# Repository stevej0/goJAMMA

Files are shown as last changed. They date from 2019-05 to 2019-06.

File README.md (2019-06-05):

# goJAMMA
Game on JAMMA development board PROTOTYPE v0.2 (C) 2019 Steve Jones / BONEYARD

This is a prototype FPGA based JAMMA board for the development of homebrew games for arcade machine platforms and superguns.

The design is currently in a prototype stage, pretty much everything has been tested as working, however bugs and performance issues may remain. This design is NOT approved for production as of yet, but the files are made public as an aid to others developing their own hardware.
  
FAQ to follow...

Hardware specifications (fixed):

Altera MAX10 10M25SAE FPGA, 25K logic elements, extended Flash features  
1MB 8Bit Static RAM, 10ns access  
16MB 8Bit HyperRAM, 166Mhz DDR, 128 byte burst  
48Mhz Crystal clock oscillator  
microSD card interface  
ADC 4 channel, 10 bit analog to digital convertor (Analog inputs via expansion connector)  
Buffered video output  
Stereo audio amplifier, 11 Watts  
PCM5101 Stereo 12S DAC  
4 Way Dip Switch  
Standard JAMMA 5v tolerant inputs, plus configuration jumpers for 6-button Pandoras Box style interface  
1x USER button, 1x RESET button  
1x USER LED  
Large long-life and user replacable through hole capacitors in the audio and voltage regulator sections  

Homebrew logic core (basic wishlist) specifications, likely to change:
  
CPU core (undecided, but a 6502 at 4Mhz currently works well)  
256 Colour palette, 320 x 240 pixel framebuffer (double buffered)  
Sprites (undecided, most likely a blitter for the framebuffer with fast HyperRAM as gfx data source)  
Layers (undecided, at least one text overlay, maybe a tiled background layer also)  
16 channel sample playback  
Ability to load programs and data from microSD fat32 formatted cards

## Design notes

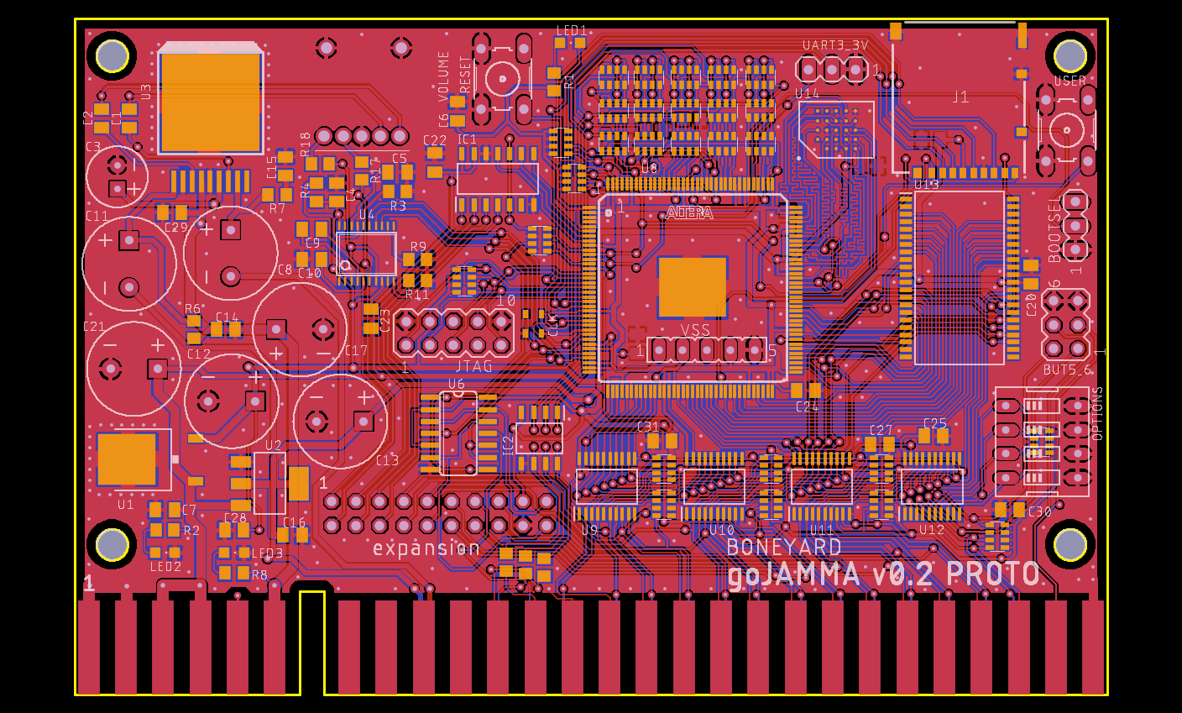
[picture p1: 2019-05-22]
pcb/goJAMMAv02a.png

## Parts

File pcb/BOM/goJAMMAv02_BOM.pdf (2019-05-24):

QTY | PART | VALUE | DEVICE | DESCRIPTION | MOUSER PART NUMBER
1 | C3 | 100uF | ULD1E101MED1TD | 100µF 25V polarized capacitor, Nichicon, 10000hr, 6.5mm x 12.5mm | 647-ULD1E101MED1TD
9 | C1, C2, C4, C5, C7, C14, C15, C16, C28 | 100nF | C0805C104M5R | CAPACITOR, KEMET, MLCC, 100nf, 50V, X7R, 0805 | 80-C0805C104M5R
2 | C9, C10 | 2u2 | C0805C225K3P | CAPACITOR, KEMET, MLCC, 2.2uf, 25V, X5R, 0805 | 80-C0805C225K3P
14 | C6, C18, C19, C20, C22, C23, C24, C25, C26, C27, C29, C30, C31, C33 | 1uF | C0805C105Z4V | CAPACITOR, KEMET, MLCC, 1uf, 16V, Y5V, 0805 | 80-C0805C105Z4V
4 | C12, C13, C17, C21 | 100uF | UBT1V101MPD8 | 100µF 35V polarized capacitor, Nichicon, 5000hr, 10mm x 12.5mm | 647-UBT1V101MPD8
2 | C8, C11 | 1000uF | EKYB250E102MJ20S | 1000µF 25V polarized capacitor, ChemiCon, 10000hr, 10mm x 20mm | 661-EKYB250E102MJ20S
3 | LED1, LED2, LED3 | LEDCHIP_0805 | 150080YS75000 | LED, 0805, YELLOW | 710-150080YS75000
1 | R2 | 150R | CRCW0805150RFKEA | RESISTOR, 150R, 0805, 1/8W, 1% | 71-CRCW0805-150-E3
1 | R8 | 560R | CRCW0805560RJNEA | RESISTOR, 560R, 0805, 1/8W, 5% | 71-CRCW0805560RJNEA
7 | R1, R2, R3, R4, R8, R9, R11 | 1K | CRCW08051K00FKEAC | RESISTOR, 1K, 0805, 1/8W, 1% | 71-CRCW08051K00FKEAC
3 | R5, R12, R13 | 0R | CRCW08050000Z0EAC | RESISTOR, 0R, 0805, 1/8W, 1% | 71-CRCW08050000Z0EAC
2 | R6, R7 | 2R7 | CRGS0805J2R7 | RESISTOR, 2.7R, 0805, 500mW, 5% | 279-CRGS0805J2R7
3 | R14, R15, R16 | 3K3 | CRCW08053K30FKEAC | RESISTOR, 3.3K, 0805, 1/8W, 1% | 71-CRCW08053K30FKEAC
2 | R17, R18 | 1M | CRCW08051M00FKEA | RESISTOR, 1M, 0805, 1/8W, 1% | 71-CRCW0805-1.0M-E3
15 | RN1, RN2, RN3, RN4, RN5, RN6, RN7, RN8, RN9, RN10, RN11, RN12, RN13, RN14, RN15 | 1k x 4 | YC164-FR-071KL | RESISTOR ARRAY 4way, 1K, 1%, 1206 | 603-YC164-FR-071KL
12 | RN16, RN17, RN18, RN19, RN20, RN21, RN22, RN23, RN24, RN26, RN27, RN28 | 1k x 4 | EXB-V8V102JV | RESISTOR ARRAY 4way, 1K, 5%, 1206 | 667-EXB-V8V102JV
1 | CLK | ECS-3225MV-480-CN-TR | ECS-3225MV-480-CN-TR | 3.3Vdc 48Mhz SMD Crystal clock oscillator 3.2 mm x 2.5 mm | 520-3225MV-480-CNT
1 | IC1 | MCP3004-I_SL | MCP3004-I_SL | A/D Converter 10Bit 4-ch 2.7V SPI SOIC14 | 579-MCP3004-I/SL
1 | IC2 | THS7314D | THS7314D | Video Amp 3-channel, SOIC8 | 595-THS7314D
1 | U1 | BA33BC0FP-E2 | BA33BC0FP-E2 | Voltage Regulator 3.3v positive, 1A, TO-252-3 | 755-BA33BC0FP-E2
1 | U2 | LM1117MPX1.8NOPB | V_REG_LM1117SOT223 | Voltage Regulator 1.8v positive, 800ma, LM1117, SOT-223-4 | 926-LM1117MPX1.8NOPB
1 | U3 | LM4755TSX/NOPB | LM4755TSX/NOPB | LM4755 Stereo Audio Amp, 11W, TO-263-9 | 926-LM4755TSX/NOPB
1 | U4 | PCM5101 | PCM5101 | Stereo Audio D/A Converter | 595-PCM5101APWR
1 | U6 | 74HC08D,653 | 74HC08D,653 | Quad 2-input AND gate, HC08 | 771-74HC08D-T
1 | U8 | 10M25SAE144C8G | 10M25SAE144C8G | ALTERA MAX10 FPGA 25K LE, FLASH, ANALOG | 989-10M25SAE144C8G
4 | U9, U10, U11, U12 | SN74LV245APWR | SN74LV245APWR | Octal Bus Transceivers With 3-State Outputs | 595-SN74LV245APWR
1 | U13 | IS61WV10248EDBLL-10TLI | IS61WV10248EDBLL-10TLI | SRAM 8M, 2.4V-3.6V, 10ns LP Async SRAM | 870-61WV10EDBLL10TLI
1 | U14 | IS66WVH16M8ALL-166B1LI | IS66WVH16M8ALL-166B1LI | DRAM 128Mb 16Mbx8 1.8V 166MHz HyperRAM | 870-WVH16M8AL166B1LI
1 | OPTIONS | SW_DIP-4 | NDS-04V | DIP SWITCH, 4 Position, Diptronics | 113-NDS-04V
2 | RESET, USER | SWITCH | B3F-1000 | OMRON TACT SWITCH 6mm x 6mm | 653-B3F-1000
1 | VOLUME | RK14J12A0A0K | RK14J12A0A0K | Potentiometers Dual Unit 14mm 3B insertion (2mm) | 688-RK14J12A0A0K
1 | J1 | DM3AT-SF-PEJM5 | DM3AT-SF-PEJM5 | DM3 RA SMT microSD memory card push/push | 798-DM3AT-SF-PEJM5
1 | JTAG | 5 x 2 | MA05-2 | PIN HEADER, 10 way
2 | BOOTSEL, UART3_3V | 3 x 1 | MA03-1 | PIN HEADER, 3 way
1 | BUT5_6 | 3 x 2 | MA03-2 | PIN HEADER, 6 way
1 | SV2 | 10 x 2 | MA10-2 | PIN HEADER, 20 way
1 | SV3 | 5 x 1 | MA05-1 | PIN HEADER, 5 way

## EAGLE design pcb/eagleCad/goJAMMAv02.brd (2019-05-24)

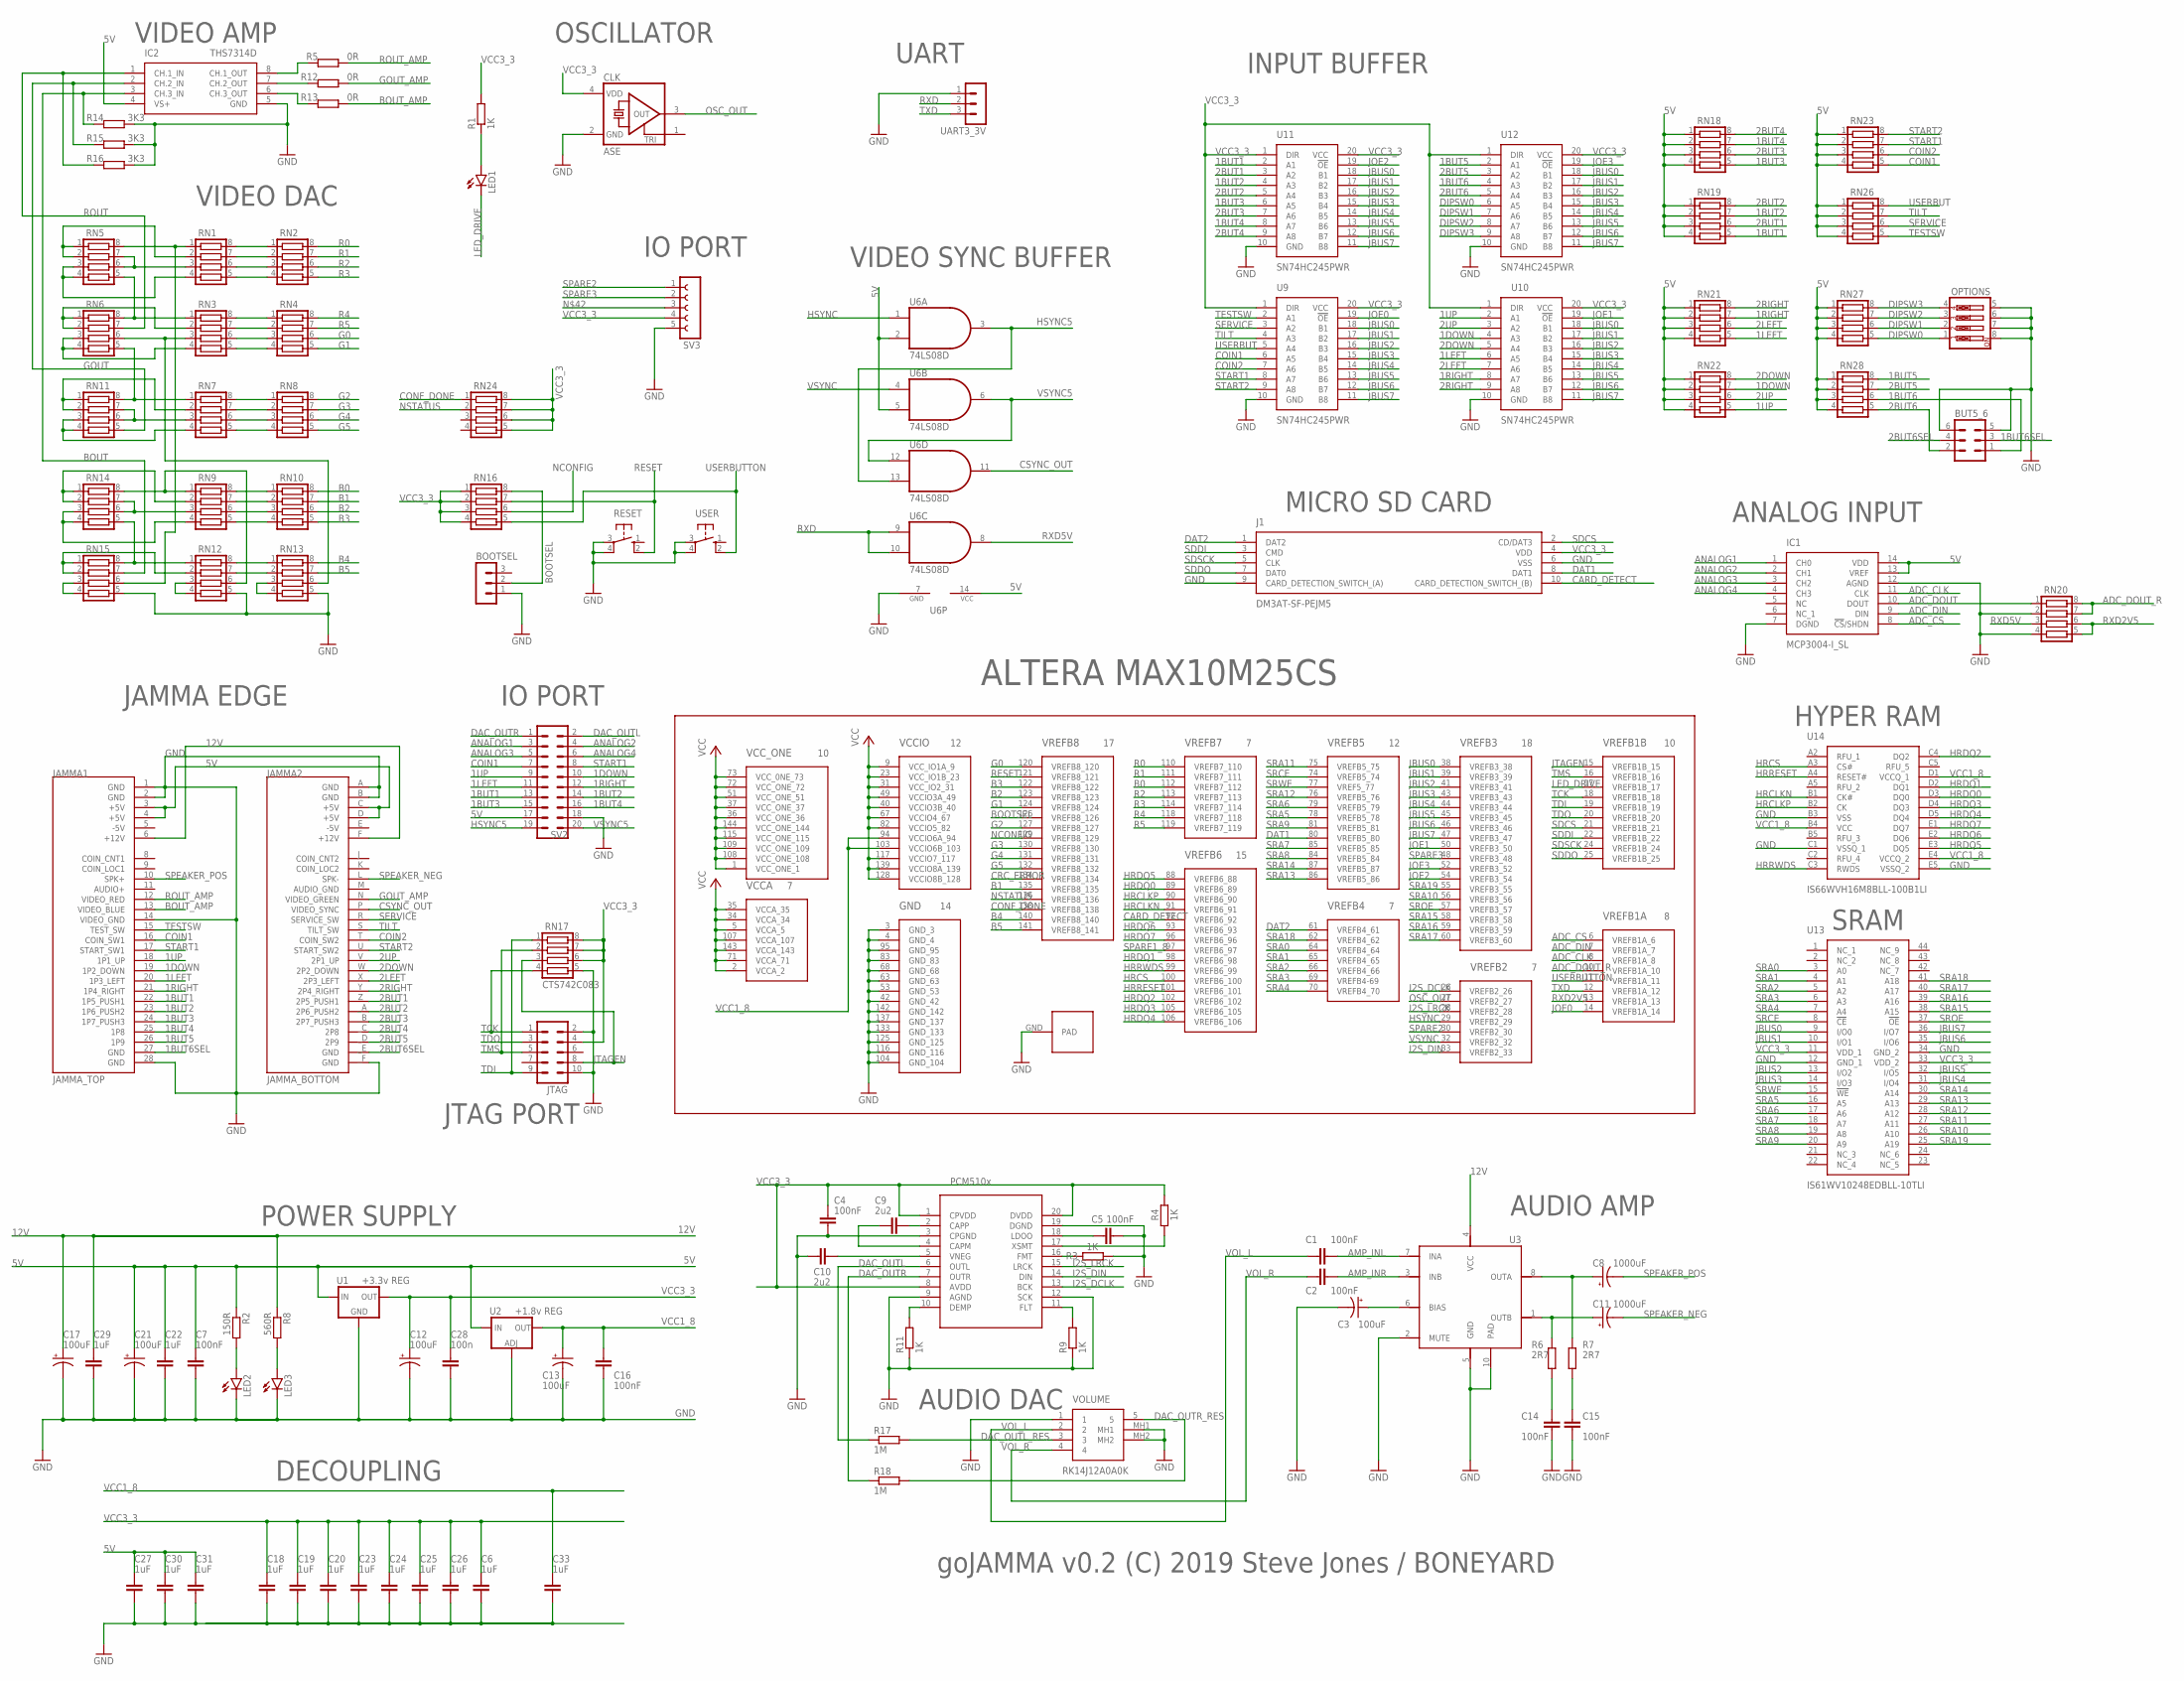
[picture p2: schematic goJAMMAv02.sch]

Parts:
BOOTSEL: MA03-1
BUT5_6: MA03-2
C1, C2, C4, C5, C7, C14, C15, C16: 100nF; C0805K
C3: 100uF; CPOL-RADIAL-2.5MM-6.5MM
C6, C18, C19, C20, C22, C23, C24, C25, C26, C27, C29, C30, C31, C33: 1uF; C0805K
C8, C11: 1000uF; CPOL-RADIAL-5MM-10MM
C9, C10: 2u2; C0805K
C12, C13, C17, C21: 100uF; CPOL-RADIAL-5MM-10MM
C28: 100n; C0805K
CLK: ASE
IC1: MCP3004-I_SL; SOIC127P600X175-14N
IC2: THS7314D; SOIC127P600X175-8N
J1: DM3AT-SF-PEJM5; DM3AT-SF-PEJM5_1
JAMMA1: JAMMA_TOP
JAMMA2: JAMMA_BOTTOM
JTAG: MA05-2
LED1, LED2, LED3: LEDCHIPLED_0805; CHIPLED_0805
OPTIONS: SW_DIP-4; EDG-04
R1, R3, R4, R9, R11: 1K; R0805
R2: 150R; R0805
R5, R12, R13: 0R; R0805
R6, R7: 2R7; R0805
R8: 560R; R0805
R14, R15, R16: 3K3; R0805
R17, R18: 1M; R0805
RESET: 10-XX; B3F-10XX
RN1, RN2, RN3, RN4, RN5, RN6, RN7, RN8, RN9, RN10, RN11, RN12, RN13, RN14, RN15, RN16, RN17, RN18, RN19, RN20, RN21, RN22, RN23, RN24, RN26, RN27, RN28: CTS742C083
SV2: MA10-2
SV3: FE05-1
U1: +3.3v REG; TO-252
U2: +1.8v REG; SOT223
U3: LM4755; DDPAK-9
U4: PCM5101; TSSOP20
U6: 74LS08D; SO14
U8: ALTERA_MAX10M25SCPAD; ALTERA_EQFP144
U9, U10, U11, U12: SN74HC245PWR; SOP65P640X120-20N
U13: IS61WV10248EDBLL-10TLI; SOP80P1176X120-44N
U14: IS66WVH16M8BLL-100B1LI; BGA24C100P5X5_600X800X120
UART3_3V: MA03-1
USER: 10-XX; B3F-10XX
VOLUME: RK14J12A0A0K

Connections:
1BUT1: JAMMA1.22 (1P5_PUSH1), RN19.5, SV2.13, U11.2 (A1)
1BUT2: JAMMA1.23 (1P6_PUSH2), RN19.7, SV2.14, U11.4 (A3)
1BUT3: JAMMA1.24 (1P7_PUSH3), RN18.5, SV2.15, U11.6 (A5)
1BUT4: JAMMA1.25 (1P8), RN18.7, SV2.16, U11.8 (A7)
1BUT5: JAMMA1.26 (1P9), RN28.8, U12.2 (A1)
1BUT6: BUT5_6.1, RN28.6, U12.4 (A3)
1BUT6SEL: BUT5_6.3, JAMMA1.27 (GND)
1DOWN: JAMMA1.19 (1P2_DOWN), RN22.7, SV2.10, U10.4 (A3)
1LEFT: JAMMA1.20 (1P3_LEFT), RN21.5, SV2.11, U10.6 (A5)
1RIGHT: JAMMA1.21 (1P4_RIGHT), RN21.7, SV2.12, U10.8 (A7)
1UP: JAMMA1.18 (1P1_UP), RN22.5, SV2.9, U10.2 (A1)
2BUT1: JAMMA2.Z (2P5_PUSH1), RN19.6, U11.3 (A2)
2BUT2: JAMMA2._A (2P6_PUSH2), RN19.8, U11.5 (A4)
2BUT3: JAMMA2._B (2P7_PUSH3), RN18.6, U11.7 (A6)
2BUT4: JAMMA2._C (2P8), RN18.8, U11.9 (A8)
2BUT5: JAMMA2._D (2P9), RN28.7, U12.3 (A2)
2BUT6: BUT5_6.2, RN28.5, U12.5 (A4)
2BUT6SEL: BUT5_6.4, JAMMA2._E (GND)
2DOWN: JAMMA2.W (2P2_DOWN), RN22.8, U10.5 (A4)
2LEFT: JAMMA2.X (2P3_LEFT), RN21.6, U10.7 (A6)
2RIGHT: JAMMA2.Y (2P4_RIGHT), RN21.8, U10.9 (A8)
2UP: JAMMA2.V (2P1_UP), RN22.6, U10.3 (A2)
5V: C7.1, C21.+, C22.1, C27.1, C30.1, C31.1, IC1.13 (VREF), IC1.14 (VDD), IC2.4 (VS+), JAMMA1.3 (+5V), JAMMA1.4 (+5V), JAMMA2.C (+5V), JAMMA2.D (+5V), R2.1, RN18.1, RN18.2, RN18.3, RN18.4, RN19.1, RN19.2, RN19.3, RN19.4, RN21.1, RN21.2, RN21.3, RN21.4, RN22.1, RN22.2, RN22.3, RN22.4, RN23.1, RN23.2, RN23.3, RN23.4, RN26.1, RN26.2, RN26.3, RN26.4, RN27.1, RN27.2, RN27.3, RN27.4, RN28.1, RN28.2, RN28.3, RN28.4, SV2.17, U1.1 (IN), U2.3 (IN), U6.2 (I1), U6.5 (I1), U6.14 (VCC)
12V: C17.+, C29.1, JAMMA1.6 (+12V), JAMMA2.F (+12V), R8.1, U3.4 (VCC)
-5V: JAMMA1.5 (-5V), JAMMA2.E (-5V)
ADC_CLK: IC1.11 (CLK), U8.8 (VREFB1A_8)
ADC_CS: IC1.8 (!CS!/SHDN), U8.6 (VREFB1A_6)
ADC_DIN: IC1.9 (DIN), U8.7 (VREFB1A_7)
ADC_DOUT: IC1.10 (DOUT), RN20.1
ADC_DOUT_R: RN20.7, RN20.8, U8.10 (VREFB1A_10)
AMP_INL: C1.2, U3.7 (INA)
AMP_INR: C2.2, U3.3 (INB)
ANALOG1: IC1.1 (CH0), SV2.3
ANALOG2: IC1.2 (CH1), SV2.4
ANALOG3: IC1.3 (CH2), SV2.5
ANALOG4: IC1.4 (CH3), SV2.6
B0: RN10.8, U8.112 (VREFB7_112)
B1: RN10.7, U8.135 (VREFB8_135)
B2: RN10.6, U8.123 (VREFB8_123)
B3: RN10.5, U8.122 (VREFB8_122)
B4: RN13.8, U8.140 (VREFB8_140)
B5: RN13.7, U8.141 (VREFB8_141)
BOOTSEL: BOOTSEL.2, RN16.8, U8.126 (VREFB8_126)
BOUT: IC2.3 (CH.3_IN), R14.2, RN15.7
BOUT_AMP: JAMMA1.13 (VIDEO_BLUE), R13.2
CARD_DETECT: J1.10 (CARD_DETECTION_SWITCH_(B)), U8.92 (VREFB6_92)
COIN1: JAMMA1.16 (COIN_SW1), RN23.5, SV2.7, U9.6 (A5)
COIN2: JAMMA2.T (COIN_SW2), RN23.6, U9.7 (A6)
CONF_DONE: RN24.1, U8.138 (VREFB8_138)
CRC_ERROR: U8.134 (VREFB8_134)
CSYNC_OUT: JAMMA2.P (VIDEO_SYNC), U6.11 (O)
DAC_OUTL: R17.1, SV2.2, U4.6 (OUTL)
DAC_OUTL_RES: R17.2, VOLUME.3
DAC_OUTR: R18.1, SV2.1, U4.7 (OUTR)
DAC_OUTR_RES: R18.2, VOLUME.5
DAT1: J1.8 (DAT1), U8.80 (VREFB5_80)
DAT2: J1.1 (DAT2), U8.61 (VREFB4_61)
DIPSW0: OPTIONS.1, RN27.5, U12.6 (A5)
DIPSW1: OPTIONS.2, RN27.6, U12.7 (A6)
DIPSW2: OPTIONS.3, RN27.7, U12.8 (A7)
DIPSW3: OPTIONS.4, RN27.8, U12.9 (A8)
G0: RN4.6, U8.120 (VREFB8_120)
G1: RN4.5, U8.124 (VREFB8_124)
G2: RN8.8, U8.127 (VREFB8_127)
G3: RN8.7, U8.130 (VREFB8_130)
G4: RN8.6, U8.131 (VREFB8_131)
G5: RN8.5, U8.132 (VREFB8_132)
GND: BOOTSEL.1, BUT5_6.5, BUT5_6.6, C3.2 (-), C4.2, C5.2, C6.2, C7.2, C10.2, C12.-, C13.-, C14.2, C15.2, C16.2, C17.-, C18.2, C19.2, C20.2, C21.-, C22.2, C23.2, C24.2, C25.2, C26.2, C27.2, C28.2, C29.2, C30.2, C31.2, C33.2, CLK.2 (GND), IC1.7 (DGND), IC1.12 (AGND), IC2.5 (GND), J1.6 (VSS), J1.9 (CARD_DETECTION_SWITCH_(A)), JAMMA1.1 (GND), JAMMA1.2 (GND), JAMMA1.14 (VIDEO_GND), JAMMA1.28 (GND), JAMMA2.A (GND), JAMMA2.B (GND), JAMMA2._F (GND), JTAG.2, JTAG.10, LED2.C, LED3.C, OPTIONS.5, OPTIONS.6, OPTIONS.7, OPTIONS.8, R3.1, R9.1, R11.1, R14.1, R15.1, R16.1, RESET.3, RESET.4 (P1), RN12.5, RN13.5, RN15.5, RN17.5, RN20.2, RN20.4, SV2.18, SV3.5, U1.3 (GND), U2.1 (ADJ), U3.2 (MUTE), U3.5 (GND), U3.10 (PAD), U4.3 (CPGND), U4.9 (AGND), U4.12 (SCK), U4.19 (DGND), U6.7 (GND), U8.3 (GND_3), U8.4 (GND_4), U8.42 (GND_42), U8.53 (GND_53), U8.63 (GND_63), U8.68 (GND_68), U8.83 (GND_83), U8.95 (GND_95), U8.104 (GND_104), U8.116 (GND_116), U8.125 (GND_125), U8.133 (GND_133), U8.137 (GND_137), U8.142 (GND_142), U8.GND (PAD), U9.10 (GND), U10.10 (GND), U11.10 (GND), U12.10 (GND), U13.12 (GND_1), U13.34 (GND_2), U14.B3 (VSS), U14.C1 (VSSQ_1), U14.E5 (VSSQ_2), UART3_3V.1, USER.3, USER.4 (P1), VOLUME.1, VOLUME.MH1, VOLUME.MH2
GOUT: IC2.2 (CH.2_IN), R15.2, RN11.5
GOUT_AMP: JAMMA2.N (VIDEO_GREEN), R12.2
HRCLKN: U8.91 (VREFB6_91), U14.B1 (CK#)
HRCLKP: U8.90 (VREFB6_90), U14.B2 (CK)
HRCS: U8.100 (VREFB6_100), U14.A3 (CS#)
HRDQ0: U8.89 (VREFB6_89), U14.D3 (DQ0)
HRDQ1: U8.98 (VREFB6_98), U14.D2 (DQ1)
HRDQ2: U8.102 (VREFB6_102), U14.C4 (DQ2)
HRDQ3: U8.105 (VREFB6_105), U14.D4 (DQ3)
HRDQ4: U8.106 (VREFB6_106), U14.D5 (DQ4)
HRDQ5: U8.88 (VREFB6_88), U14.E3 (DQ5)
HRDQ6: U8.93 (VREFB6_93), U14.E2 (DQ6)
HRDQ7: U8.96 (VREFB6_96), U14.E1 (DQ7)
HRRESET: U8.101 (VREFB6_101), U14.A4 (RESET#)
HRRWDS: U8.99 (VREFB6_99), U14.C3 (RWDS)
HSYNC: U6.1 (I0), U8.29 (VREFB2_29)
HSYNC5: SV2.19, U6.3 (O), U6.13 (I1)
I2S_DCLK: U4.13 (BCK), U8.26 (VREFB2_26)
I2S_DIN: U4.14 (DIN), U8.33 (VREFB2_33)
I2S_LRCK: U4.15 (LRCK), U8.28 (VREFB2_28)
JBUS0: U8.38 (VREFB3_38), U9.18 (B1), U10.18 (B1), U11.18 (B1), U12.18 (B1), U13.9 (I/O0)
JBUS1: U8.39 (VREFB3_39), U9.17 (B2), U10.17 (B2), U11.17 (B2), U12.17 (B2), U13.10 (I/O1)
JBUS2: U8.41 (VREFB3_41), U9.16 (B3), U10.16 (B3), U11.16 (B3), U12.16 (B3), U13.13 (I/O2)
JBUS3: U8.43 (VREFB3_43), U9.15 (B4), U10.15 (B4), U11.15 (B4), U12.15 (B4), U13.14 (I/O3)
JBUS4: U8.44 (VREFB3_44), U9.14 (B5), U10.14 (B5), U11.14 (B5), U12.14 (B5), U13.31 (I/O4)
JBUS5: U8.45 (VREFB3_45), U9.13 (B6), U10.13 (B6), U11.13 (B6), U12.13 (B6), U13.32 (I/O5)
JBUS6: U8.46 (VREFB3_46), U9.12 (B7), U10.12 (B7), U11.12 (B7), U12.12 (B7), U13.35 (I/O6)
JBUS7: U8.47 (VREFB3_47), U9.11 (B8), U10.11 (B8), U11.11 (B8), U12.11 (B8), U13.36 (I/O7)
JOE0: U8.14 (VREFB1A_14), U9.19 (!OE)
JOE1: U8.50 (VREFB3_50), U10.19 (!OE)
JOE2: U8.54 (VREFB3_54), U11.19 (!OE)
JOE3: U8.52 (VREFB3_52), U12.19 (!OE)
JTAGEN: JTAG.8, RN17.3, U8.15 (VREFB1B_15)
LED_DRIVE: LED1.C, U8.17 (VREFB1B_17)
unnamed: RN1.8, RN2.1
unnamed: C8.+, R7.2, U3.8 (OUTA)
unnamed: RN1.7, RN2.2
unnamed: RN1.6, RN2.3
unnamed: RN1.5, RN2.4
unnamed: RN3.8, RN4.1
unnamed: RN3.7, RN4.2
unnamed: RN7.8, RN8.1
unnamed: RN7.7, RN8.2
unnamed: RN7.6, RN8.3
unnamed: RN7.5, RN8.4
unnamed: RN6.5, RN7.1, RN11.8
unnamed: RN9.8, RN10.1
unnamed: RN1.1, RN5.8, RN15.6
unnamed: RN1.2, RN5.1, RN5.2
unnamed: RN1.3, RN5.6, RN5.7
unnamed: RN1.4, RN5.3, RN5.4
unnamed: RN3.1, RN5.5, RN6.8
unnamed: RN3.2, RN6.1, RN6.2
unnamed: RN9.7, RN10.2
unnamed: RN7.2, RN11.1, RN11.2
unnamed: RN7.3, RN11.6, RN11.7
unnamed: RN7.4, RN11.3, RN11.4
unnamed: RN9.6, RN10.3
unnamed: RN9.5, RN10.4
unnamed: RN3.4, RN6.3, RN6.4
unnamed: RN12.8, RN13.1
unnamed: RN3.6, RN4.3
unnamed: RN3.5, RN4.4
unnamed: RN3.3, RN6.6, RN13.6
unnamed: RN12.7, RN13.2
unnamed: RN9.1, RN12.6, RN14.8
unnamed: RN9.2, RN14.1, RN14.2
unnamed: RN9.3, RN14.6, RN14.7
unnamed: RN9.4, RN14.3, RN14.4
unnamed: RN12.1, RN14.5, RN15.8
unnamed: RN12.2, RN15.1, RN15.2
unnamed: RN15.3, RN15.4
unnamed: RN12.3, RN12.4
unnamed: RN13.3, RN13.4
unnamed: R3.2, U4.16 (FMT)
unnamed: IC2.8 (CH.1_OUT), R5.1
unnamed: LED1.A, R1.1
unnamed: IC2.7 (CH.2_OUT), R12.1
unnamed: IC2.6 (CH.3_OUT), R13.1
unnamed: LED2.A, R2.2
unnamed: LED3.A, R8.2
unnamed: C9.2, U4.2 (CAPP)
unnamed: C9.1, U4.4 (CAPM)
unnamed: C11.+, R6.2, U3.1 (OUTB)
unnamed: C3.1 (+), U3.6 (BIAS)
unnamed: C14.1, R6.1
unnamed: C15.1, R7.1
unnamed: C10.1, U4.5 (VNEG)
unnamed: R4.1, U4.17 (XSMT)
unnamed: R11.2, U4.10 (DEMP)
unnamed: R9.2, U4.11 (FLT)
unnamed: C5.1, U4.18 (LDOO)
NCONFIG: RN16.6, U8.129 (VREFB8_129)
NSTATUS: RN24.2, U8.136 (VREFB8_136)
OSC_OUT: CLK.3 (OUT), U8.27 (VREFB2_27)
R0: RN2.8, U8.110 (VREFB7_110)
R1: RN2.7, U8.111 (VREFB7_111)
R2: RN2.6, U8.113 (VREFB7_113)
R3: RN2.5, U8.114 (VREFB7_114)
R4: RN4.8, U8.118 (VREFB7_118)
R5: RN4.7, U8.119 (VREFB7_119)
RESET: RESET.2 (S1), RN16.7, U8.121 (VREFB8_121)
ROUT: IC2.1 (CH.1_IN), R16.2, RN6.7
ROUT_AMP: JAMMA1.12 (VIDEO_RED), R5.2
RXD: U6.9 (I0), U6.10 (I1), UART3_3V.2
RXD2V5: RN20.5, RN20.6, U8.13 (VREFB1A_13)
RXD5V: RN20.3, U6.8 (O)
SDCS: J1.2 (CD/DAT3), U8.21 (VREFB1B_21)
SDDI: J1.3 (CMD), U8.22 (VREFB1B_22)
SDDO: J1.7 (DAT0), U8.25 (VREFB1B_25)
SDSCK: J1.5 (CLK), U8.24 (VREFB1B_24)
SERVICE: JAMMA2.R (SERVICE_SW), RN26.6, U9.3 (A2)
SPARE1_8: U8.97 (VREFB6_97)
SPARE2: SV3.1, U8.30 (VREFB2_30)
SPARE3: SV3.2, U8.48 (VREFB3_48)
SPEAKER_NEG: C11.-, JAMMA2.L (SPK-)
SPEAKER_POS: C8.-, JAMMA1.10 (SPK+)
SRA0: U8.64 (VREFB4_64), U13.3 (A0)
SRA1: U8.65 (VREFB4_65), U13.4 (A1)
SRA2: U8.66 (VREFB4_66), U13.5 (A2)
SRA3: U8.69 (VREFB4-69), U13.6 (A3)
SRA4: U8.70 (VREFB4_70), U13.7 (A4)
SRA5: U8.78 (VREFB5_78), U13.16 (A5)
SRA6: U8.79 (VREFB5_79), U13.17 (A6)
SRA7: U8.85 (VREFB5_85), U13.18 (A7)
SRA8: U8.84 (VREFB5_84), U13.19 (A8)
SRA9: U8.81 (VREFB5_81), U13.20 (A9)
SRA10: U8.56 (VREFB3_56), U13.26 (A10)
SRA11: U8.75 (VREFB5_75), U13.27 (A11)
SRA12: U8.76 (VREFB5_76), U13.28 (A12)
SRA13: U8.86 (VREFB5_86), U13.29 (A13)
SRA14: U8.87 (VREFB5_87), U13.30 (A14)
SRA15: U8.58 (VREFB3_58), U13.38 (A15)
SRA16: U8.59 (VREFB3_59), U13.39 (A16)
SRA17: U8.60 (VREFB3_60), U13.40 (A17)
SRA18: U8.62 (VREFB4_62), U13.41 (A18)
SRA19: U8.55 (VREFB3_55), U13.25 (A19)
SRCE: U8.74 (VREFB5_74), U13.8 (!CE)
SROE: U8.57 (VREFB3_57), U13.37 (!OE)
SRWE: U8.77 (VREF5_77), U13.15 (!WE)
START1: JAMMA1.17 (START_SW1), RN23.7, SV2.8, U9.8 (A7)
START2: JAMMA2.U (START_SW2), RN23.8, U9.9 (A8)
TCK: JTAG.1, RN17.4, U8.18 (VREFB1B_18)
TDI: JTAG.9, RN17.1, U8.19 (VREFB1B_19)
TDO: JTAG.3, U8.20 (VREFB1B_20)
TESTSW: JAMMA1.15 (TEST_SW), RN26.5, U9.2 (A1)
TILT: JAMMA2.S (TILT_SW), RN26.7, U9.4 (A3)
TMS: JTAG.5, RN17.2, U8.16 (VREFB1B_16)
TXD: U8.12 (VREFB1A_12), UART3_3V.3
USERBUT: RN26.8, U9.5 (A4)
USERBUTTON: RN16.5, U8.11 (VREFB1A_11), USER.2 (S1)
VCC1_8: C13.+, C16.1, C33.1, U2.2 (OUT), U2.4 (OUT), U8.94 (VCCIO6A_94), U8.103 (VCCIO6B_103), U14.B4 (VCC), U14.D1 (VCCQ_1), U14.E4 (VCCQ_2)
VCC3_3: C4.1, C6.1, C12.+, C18.1, C19.1, C20.1, C23.1, C24.1, C25.1, C26.1, C28.1, CLK.4 (VDD), J1.4 (VDD), JTAG.4, R1.2, R4.2, RN16.1, RN16.2, RN16.3, RN16.4, RN17.6, RN17.7, RN17.8, RN24.5, RN24.6, RN24.7, RN24.8, SV3.4, U1.2 (OUT), U4.1 (CPVDD), U4.8 (AVDD), U4.20 (DVDD), U8.1 (VCC_ONE_1), U8.2 (VCCA_2), U8.5 (VCCA_5), U8.9 (VCC_IO1A_9), U8.23 (VCC_IO1B_23), U8.31 (VCC_IO2_31), U8.34 (VCCA_34), U8.35 (VCCA_35), U8.36 (VCC_ONE_36), U8.37 (VCC_ONE_37), U8.40 (VCCIO3B_40), U8.49 (VCCIO3A_49), U8.51 (VCC_ONE_51), U8.67 (VCCIO4_67), U8.71 (VCCA_71), U8.72 (VCC_ONE_72), U8.73 (VCC_0NE_73), U8.82 (VCCIO5_82), U8.107 (VCCA_107), U8.108 (VCC_ONE_108), U8.109 (VCC_ONE_109), U8.115 (VCC_ONE_115), U8.117 (VCCIO7_117), U8.128 (VCCIO8B_128), U8.139 (VCCIO8A_139), U8.143 (VCCA_143), U8.144 (VCC_ONE_144), U9.1 (DIR), U9.20 (VCC), U10.1 (DIR), U10.20 (VCC), U11.1 (DIR), U11.20 (VCC), U12.1 (DIR), U12.20 (VCC), U13.11 (VDD_1), U13.33 (VDD_2)
VOL_L: C1.1, VOLUME.2
VOL_R: C2.1, VOLUME.4
VSYNC: U6.4 (I0), U8.32 (VREFB2_32)
VSYNC5: SV2.20, U6.6 (O), U6.12 (I0)

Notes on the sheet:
IO PORT
JAMMA EDGE
JTAG PORT
AUDIO DAC
AUDIO AMP
ANALOG INPUT
HYPER RAM
SRAM
UART
MICRO SD CARD
INPUT BUFFER
VIDEO AMP
VIDEO DAC
POWER SUPPLY
DECOUPLING
VIDEO SYNC BUFFER
OSCILLATOR
goJAMMA v0.2 (C) 2019 Steve Jones / BONEYARD

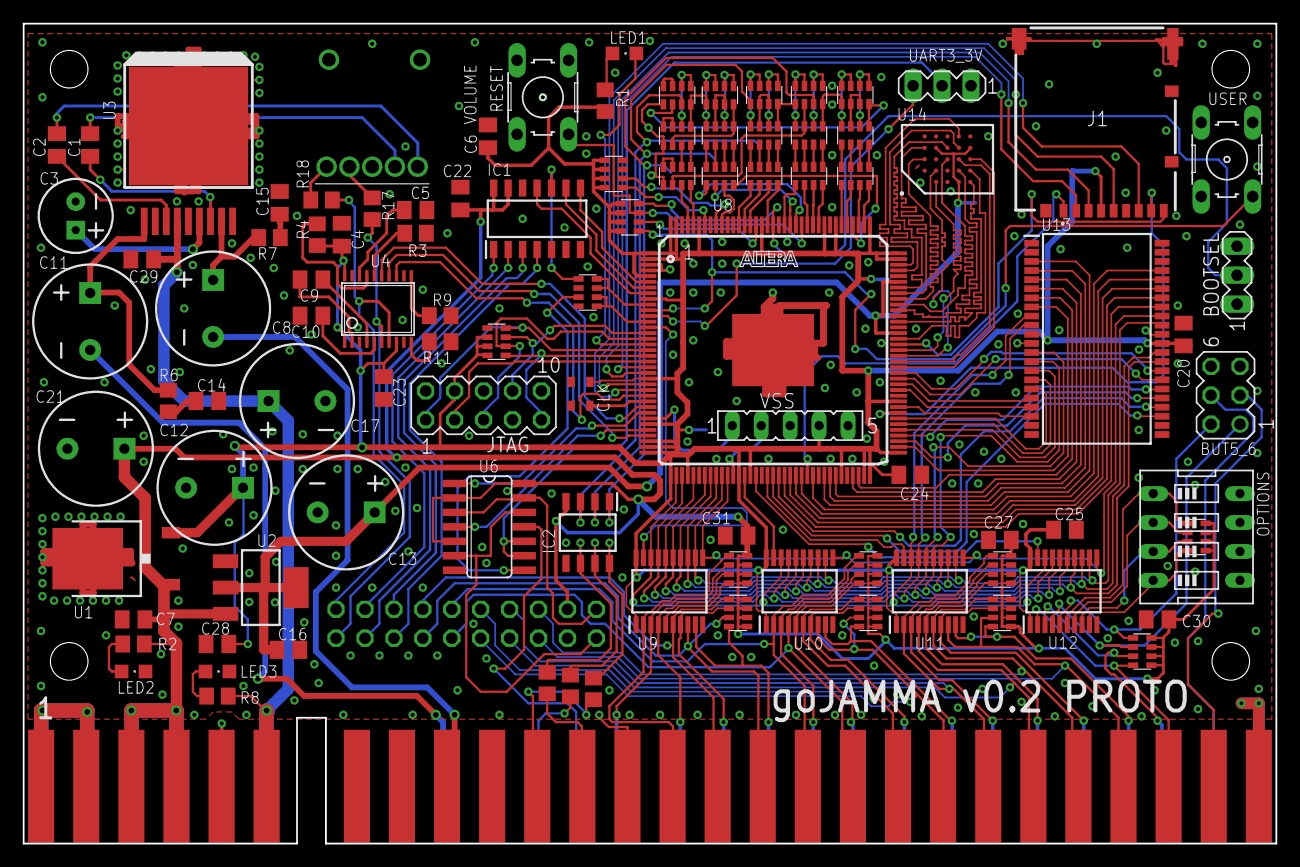
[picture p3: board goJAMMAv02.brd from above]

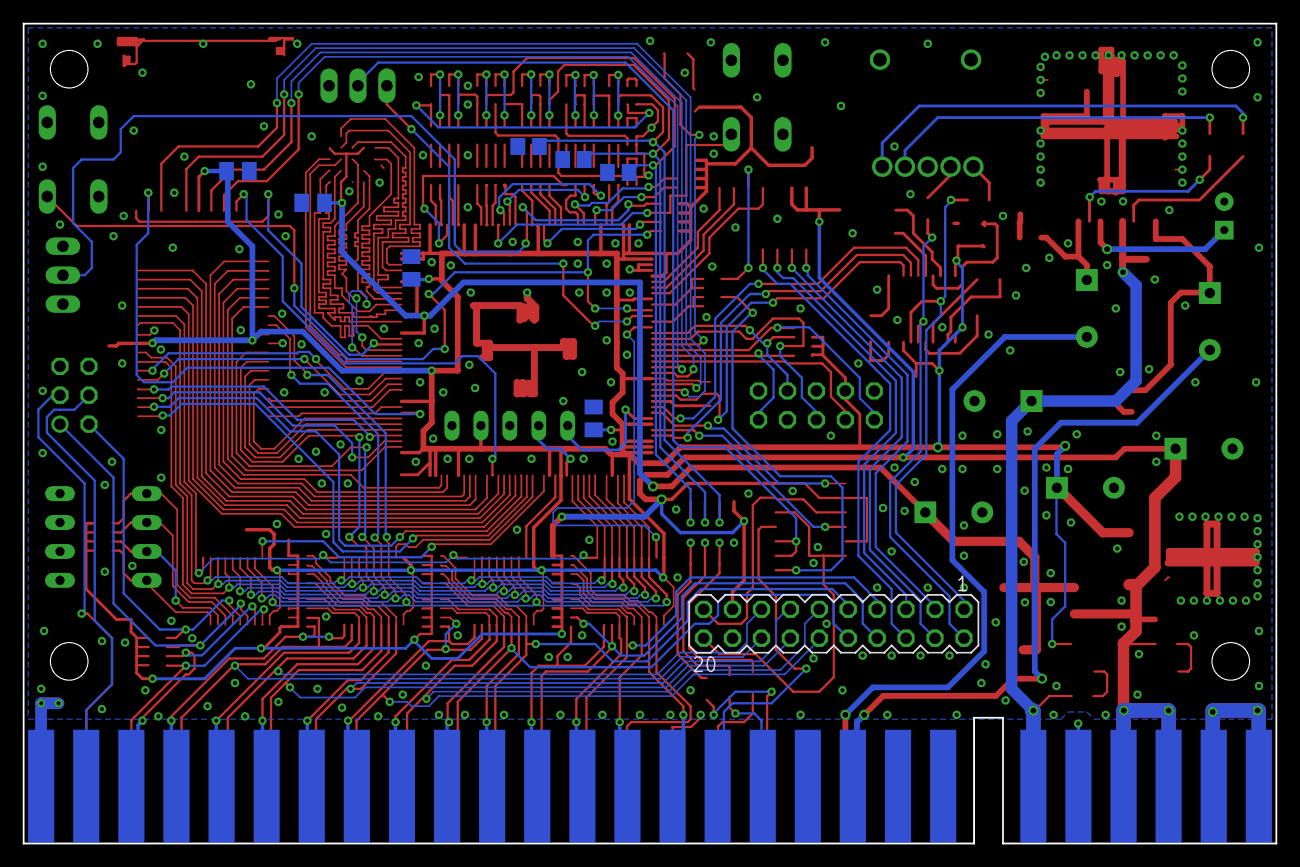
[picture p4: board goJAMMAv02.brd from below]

Board: 2 copper layers, 110.0 x 72.0 mm, 111 parts (8 on the bottom side), 223 nets.

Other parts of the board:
E$1, E$2, E$8, E$9: STAND-OFF

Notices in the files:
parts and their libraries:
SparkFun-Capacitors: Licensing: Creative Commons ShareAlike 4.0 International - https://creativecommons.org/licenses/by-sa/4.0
